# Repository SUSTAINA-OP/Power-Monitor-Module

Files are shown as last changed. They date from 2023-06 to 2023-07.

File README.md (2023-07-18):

<html lang="en">

<head>
	<meta charset="uft-8">
	<meta name="author" content="Masato Kubotera">
    <meta name="description" content="">
</head>

<body>
    <p><strong>This product is currently under development!</strong></p>
	<h1>Power Monitor Module</h1>
        <p>
            This product is a high-side sensing current/voltage monitor module. The sensing voltage is 0~36V and the current is ±20A. The operating voltage is 2.7~5.5V, and these values are available via I<sup>2</sup>C I/F. The slave address is selectable on the board, and up to 16 modules in total are connected.<br>
            <br>
            This product has been verified to be able to acquire current and voltage values using the following Arduino library.
            <ul>
                <li><a href="https://github.com/asukiaaa/INA226_asukiaaa">asukiaaa/INA226_asukiaaa</a></li>
            </ul>
            SUSTAINA-OP<sup>TM</sup> connects to Jetson Xavier NX through a carrier board and obtains values using the following library.
            <ul>
                <li><a href="https://github.com/hiroki-0001/INA226_Library">hiroki-0001/INA226_Library</a></li>
            </ul>
        </p>
	<h2>Features Rev. 2</h2>
        <p>
            <table>
                <tr>
                    <th>Top Surface of PCB</th>
                    <th>Bottom Surface of PCB</th>
                    <th>Assembled Electronic Components</th>
                </tr>
                <tr>
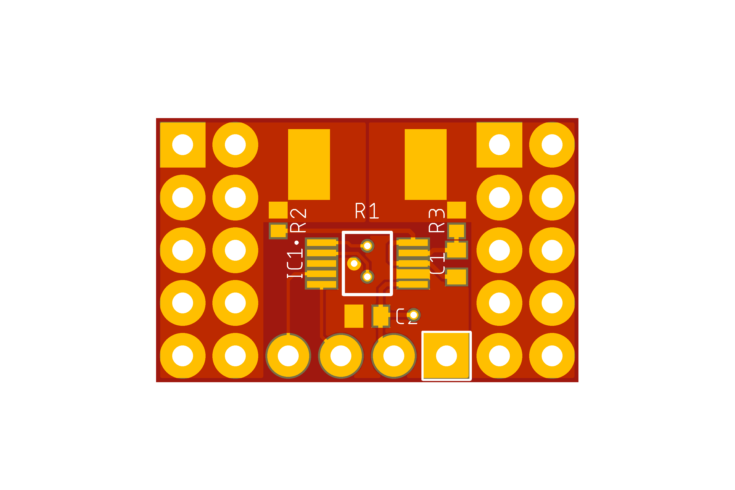
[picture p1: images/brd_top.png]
                    <td></td>
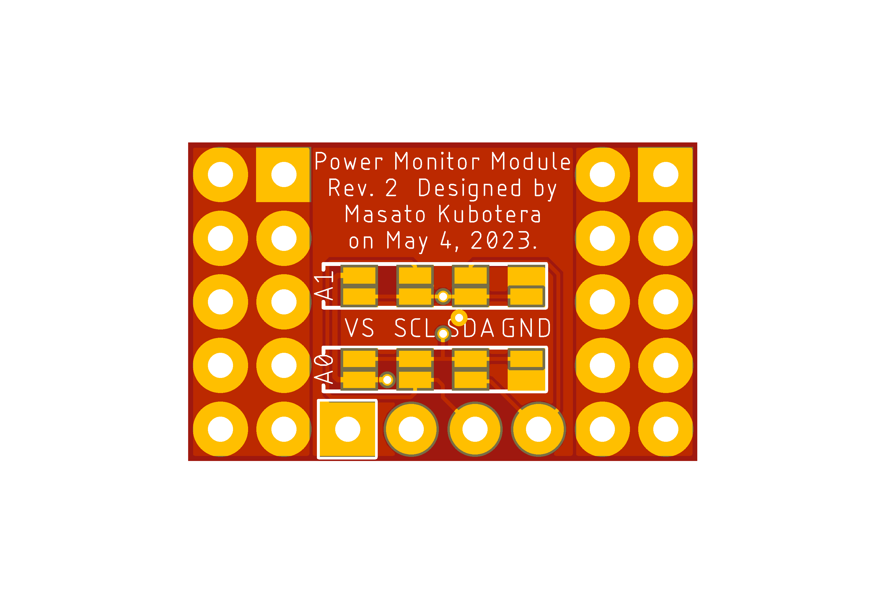
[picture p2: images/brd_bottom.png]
                    <td></td>
                    <td></td>
                </tr>
            </table>
        </p>
    <h3>PCB</h3>
        <p>
            <ul>
                <li>8" x 5" (20.32mm x 12.7mm) PCB layout</li>
                <li>1" (2.54mm) pitch through-holes for pin headers
                    <ul>
                        <li>2 x 5 pin headers - 1
                            <ul>
                                <li><strong>VIN+</strong>: Power input side</li>
                            </ul>
                        </li>
                        <li>2 x 5 pin headers - 2
                            <ul>
                                <li><strong>VIN-</strong>: Load side</li>
                            </ul>
                        </li>
                        <li>1 x 4 pin headers: I<sup>2</sup>C Interface
                            <ul>
                                <li><strong>SDA</strong>: Serial bus data line</li>
                                <li><strong>SCL</strong>: Serial bus clock line</li>
                                <li><strong>VS</strong>: Supply voltage</li>
                                <li><strong>GND</strong>: Common Ground</li>
                            </ul>
                        </li>
                    </ul>
                </li>
            </ul>
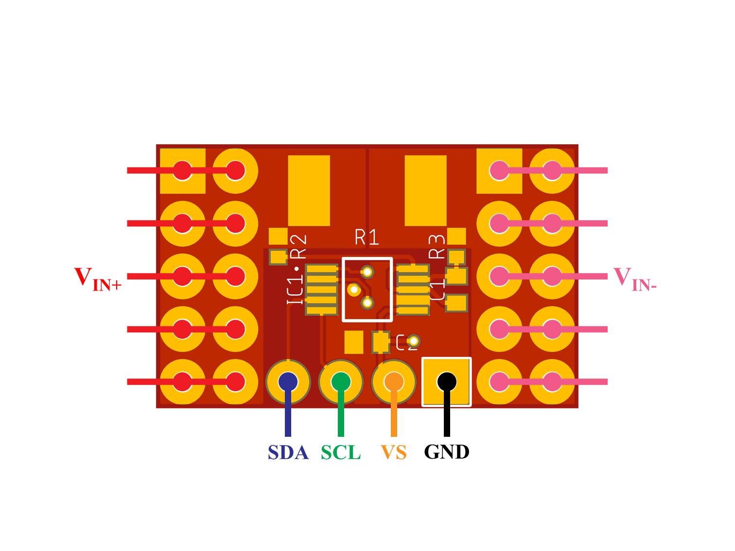
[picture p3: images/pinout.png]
            
        </p>
    <h3><a href="https://www.ti.com/product/en-us/INA226">Texas Instruments INA226</a></h3>
        <p>
            <ul>
                <li>Bus voltage sensing from 0 V to 36 V</li>
                <li>Power-supply operation: 2.7 V to 5.5 V</li>
                <li>High accuracy:
                    <ul>
                        <li>Gain error: 0.1% (maximum)</li>
                        <li>Offset: 10 μV (maximum)</li>
                    </ul>
                </li>
            </ul>
            Note: The I<sup>2</sup>C address of this product is selectable from 16 addresses by the short lands on the board.
        <p>
	<h2>Development Environments</h2>
    <p>
        This product is designed with the following software.
            <ul>
                <li><a href="https://www.autodesk.com/products/eagle/overview">Autodesk Eagle 9.6.2</a></li>
            </ul>
    </p>
    <h2>Repository Contents</h2>
        <p>
            <dl>
                <dt><a href="/images">\images</a></dt>
                <dd>PCB preview images and capture of design screen</dd>
                <dt><a href="/libraries">\libraries</a></dt>
                <dd>Libraries used in Autodesk Eagle design</dd>
                <dt><a href="/pcb_order">\pcb_order</a> </dt>
                <dd>Gerber data and documentation for ordering PCB</dd>
                <dt><a href="/schematic.pdf">schematic.pdf</a></dt>
                <dd>Circuit diagram of this product</dd>
                <dt>*.brd</dt>
                <dd>Board wiring design file by Autodesk Eagle</dd>
                <dt>*.sch</dt>
                <dd>Circuit diagram design file by Autodesk Eagle</dd>
                <dt><a href="/.gitignore">.gitignore</a></dt>
                <dd>A file that tells Git not to track a particular file</dd>            <dt><a href="/LICENSE">LICENSE</a></dt>
                <dd>License to use this product</dd>
            </dl>
        </p>
    <h2>Documentation</h2>
        <p>
            The following documents are available for this product.
            <ul>
                <li><a href="/pcb_order/README.md">\pcb_order\README.md</a>: Information for ordering the PCB or PCBA</li>
            </ul>
        </p>
    <h2>References</h2>
        <p>
            This product was designed with reference to the following products.
            <ul>
                <li><a href="https://www.ti.com/tool/ja-jp/INA226EVM">Texas Instruments INA226EVM: INA226 evaluation module</a></li>
                <li><a href="https://strawberry-linux.com/catalog/items?code=12031">Strawberry Linux INA226: I2C digital current, voltage, and power meter module (up to 20A)</a></li>
            </ul>
        </p>
    <h2>Contact</h2>
        <p>
            If you have any questions, please contact the designer of this product, Masato Kubodera, by <a href="mailto:masato.kubotera@sustaina-op.com">e-mail</a>.<br>
            E-mail: <a href="mailto:masato.kubotera@sustaina-op.com">masato.kubotera@sustaina-op.com</a>
        </p>
    <h2>License Information</h2>
        <p>
            This product is open source. Please review the <a href="/LICENSE">LICENSE</a> for license information.<br>
            <br>
            This product by Masato Kubotera is licensed under a <a href="http://creativecommons.org/licenses/by-nc-sa/4.0/">Creative Commons Attribution-NonCommercial-ShareAlike 4.0 International License</a>.
        </p>
</body>
</html>

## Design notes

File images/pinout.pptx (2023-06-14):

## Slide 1


VIN+

VIN-

SDA

SCL

GND

VS

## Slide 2

SDA

SCL

VS

GND

Power Monitor Module

VIN+

VIN-

Power Supply
0 V to 36V

GND

Load
Max. 20A

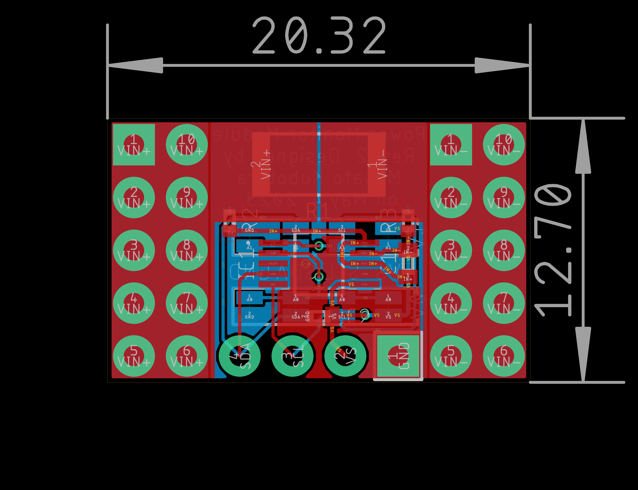
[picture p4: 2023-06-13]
images/brd.png

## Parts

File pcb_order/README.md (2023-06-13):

<html lang="en">

<head>
	<meta charset="uft-8">
	<meta name="author" content="Masato Kubotera">
    <meta name="description" content="">
</head>

<body>
	<h1>PCB / PCBA Order</h1>
        <p>
            PCB/PCBA ordering were outsourced to <a href="https://jlcpcb.com/">JLCPCB</a>.<br>
            The following files were used to generate files for PCB/PCBA orders.
            <ul>
                <li>Eagle Design File:
                    <a href="https://github.com/JLCPCB/jlcpcb-eagle/blob/master/design%20rules/jlcpcb-2layers.dru">jlcpcb-2layers.dru</a>
                </li>
                <li>Eagle CAM File:
                    <a href="https://github.com/JLCPCB/jlcpcb-eagle/blob/master/cam/jlcpcb_2_layer_v9.cam">jlcpcb_2_layer_v9.cam</a>
                </li>
                <li>BOM/CPL Exporter ULPs:
                    <a href="https://github.com/JLCPCB/jlcpcb-eagle/blob/master/ulps/jlcpcb_smta_exporter.ulp">jlcpcb_smta_exporter.ulp</a>
                </li>
            </ul>
            These are distributed in <a href="https://github.com/JLCPCB/jlcpcb-eagle">github.com/JLCPCB/jlcpcb-eagle</a>.<br>
        </p>
    <h2>PCB Order Specifications</h2>
        <p>           
            <table>
                <tr>
                    <th>PCB Top Image</th>
                    <th>PCB Bottom Image</th>
                </tr>
                <tr>
                    <td></td>
                    <td></td>
                </tr>
            </table>
            The following  files used to order the PCB and their specifications. 
            <ul>
                <li>Gerber data: <a href="Gerber_date.zip">Gerber_date.zip</a></li>
            </ul>
            <details close>
                <summary>Click for more specifications</summary>
                <ul>                
                    <li>Base Material: FR-4</li>
                    <li>Layers: 2</li>
                    <li>Dimension: 20.32 mm* 12.7 mm</li>
                    <li>Product Type: Industrial/Consumer electronics</li>
                    <li>Different Design: 1</li>
                    <li>Delivery Format: Single PCB</li>
                    <li>PCB Thickness: 1.6</li>
                    <li>Impedance Control: no</li>
                    <li>PCB Color: Red</li>
                    <li>Silkscreen: White</li>
                    <li>Surface Finish: HASL(with lead)</li>
                    <li>Outer Copper Weight: 1 oz</li>
                    <li>Via Covering: Tented</li>
                    <li>Board Outline Tolerance: ±0.2mm(Regular)</li>
                    <li>Confirm Production file: No</li>                
                    <li>Remove Order Number: Yes</li>
                    <li>Deburring/Edge rounding: No</li>
                    <li>Flying Probe Test: Fully Test</li>
                    <li>Gold Fingers: No</li>
                    <li>Castellated Holes: No</li>
                    <li>4-Wire Kelvin Test: No</li>
                    <li>Paper between PCBs: No</li>
                    <li>Appearance Quality: IPC Class 2 Standard</li>
                    <li>Silkscreen Technology: Ink-jet/Screen Printing</li>
                    <li>Package Box: With JLCPCB logo</li>
                </ul>
            </details>
        </p>
    <h2>PCBA Order Specifications</h2>
        <p>
            <table>
                <tr><th>PCBA Image</th></tr>
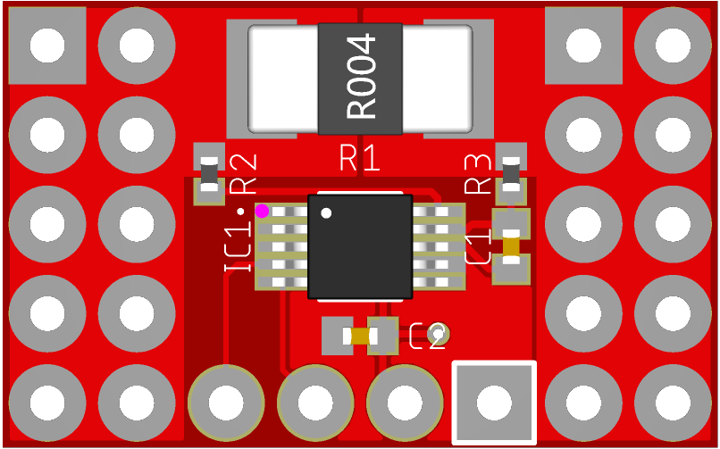
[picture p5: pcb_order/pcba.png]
                <tr><td></td></tr>
            </table>
            The following files used to order the PCBA and their specifications.
            <ul>
                <li>BOM File: <a href="Power-Monitor-Module_top_bom.csv">Power-Monitor-Module_top_bom.csv</a></li>
                <li>CPL File: <a href="Power-Monitor-Module_top_cpl.csv">Power-Monitor-Module_top_cpl.csv</a></li>
            </ul>
            The following parts are attached in the PCBA.
            <table>
                <tr>
                    <th>Part Image</th>
                    <th>Top Designator</th>
                    <th>MFR.Part #</th>
                    <th>JLCPCB Part #</th>
                    <th>Manufacturer</th>
                    <th>Part Detail</th>
                </tr>
                <tr>
                    <td></td>
                    <td>C1,C2</td>
                    <td>CC0402JRX7R7BB104</td>
                    <td><a href="https://jlcpcb.com/partdetail/Yageo-CC0402JRX7R7BB104/C541464">C541464</a></td>
                    <td>Murata Electronics</td>
                    <td>Multilayer Ceramic Capacitor SMD 100nF 16V ±5% X7R 0402</td>
                </tr>
                <tr>
                    <td></td>
                    <td>IC1</td>
                    <td>INA226AIDGSR</td>
                    <td><a href="https://jlcpcb.com/partdetail/TexasInstruments-INA226AIDGSR/C49851">C49851</a></td>
                    <td>Texas Instruments</td>
                    <td>Output Current/Voltage/Power Monitor 36V 16-bit MSOP-10</td>
                </tr>
                <tr>
                    <td></td>
                    <td>R1</td>
                    <td>LMP25NF3P0R002S</td>
                    <td><a href="https://jlcpcb.com/partdetail/Prosemi-LMP25NF3P0R002S/C2838967">C2838967</a></td>
                    <td>prosemi</td>
                    <td>Current Sensing Resistors SMD 2mΩ 3W ±1% 2512</td>
                </tr>
                <tr>
                    <td></td>
                    <td>R2,R3</td>
                    <td>RC0402FR-074R7L</td>
                    <td><a href="https://jlcpcb.com/partdetail/Yageo-RC0402FR074R7L/C137962">C137962</a></td>
                    <td>YAGEO</td>
                    <td>Thick Film Resistor SMD 4.7Ω 62.5mW ±1% 0402</td>
                </tr>
            </table>
            These selected parts are listed in <a href="bom.xls">bom.xls</a>.<br>
            <details close>
                <summary>Click for more specifications</summary>
                <ul>                
                    <li>PCBA Type: Economic</li>
                    <li>Assembly Side: Top Side</li>
                    <li>Tooling holes: Added by JLCPCB</li>
                    <li>Confirm Parts Placement: No</li>
                </ul>
            </details>
        </p>
    </body>
</html>

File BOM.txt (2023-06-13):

Qty Value     Device     Package   Parts                                  Description                
1   0.002     R-US_R2512 R2512     R1                                     RESISTOR, American symbol  
2   0.1u      C-EUC0402  C0402     C1, C2                                 CAPACITOR, European symbol 
1   1X4P      1X4P       1X4P      P3                                                                
2   2X5P      2X5P       2X5P      P1, P2                                                            
2   4.7       R-US_R0402 R0402     R2, R3                                 RESISTOR, American symbol  
1   INA226    INA226     MSOP-10   IC1                                                               
8   SHORTLAND SHORTLAND  SHORTLAND JP1, JP2, JP3, JP4, JP5, JP6, JP7, JP8

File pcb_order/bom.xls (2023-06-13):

Comment | Designator | Footprint | JLCPCB Part #
0.002 | R1 | R2512 | C2838967
0.1u | C1,C2 | C0402 | C541464
4.7 | R2,R3 | R0402 | C137962
INA226 | IC1 | INA226 | C49851

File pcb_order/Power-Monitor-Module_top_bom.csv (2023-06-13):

Comment | Designator | Footprint | LCSC Part #
0.1u | C1 C2 | C0402 | C541464
0.002 | R1 | R2512 | C2838967
4.7 | R2 R3 | R0402 | C137962
INA226 | IC1 | MSOP-10 | C49851

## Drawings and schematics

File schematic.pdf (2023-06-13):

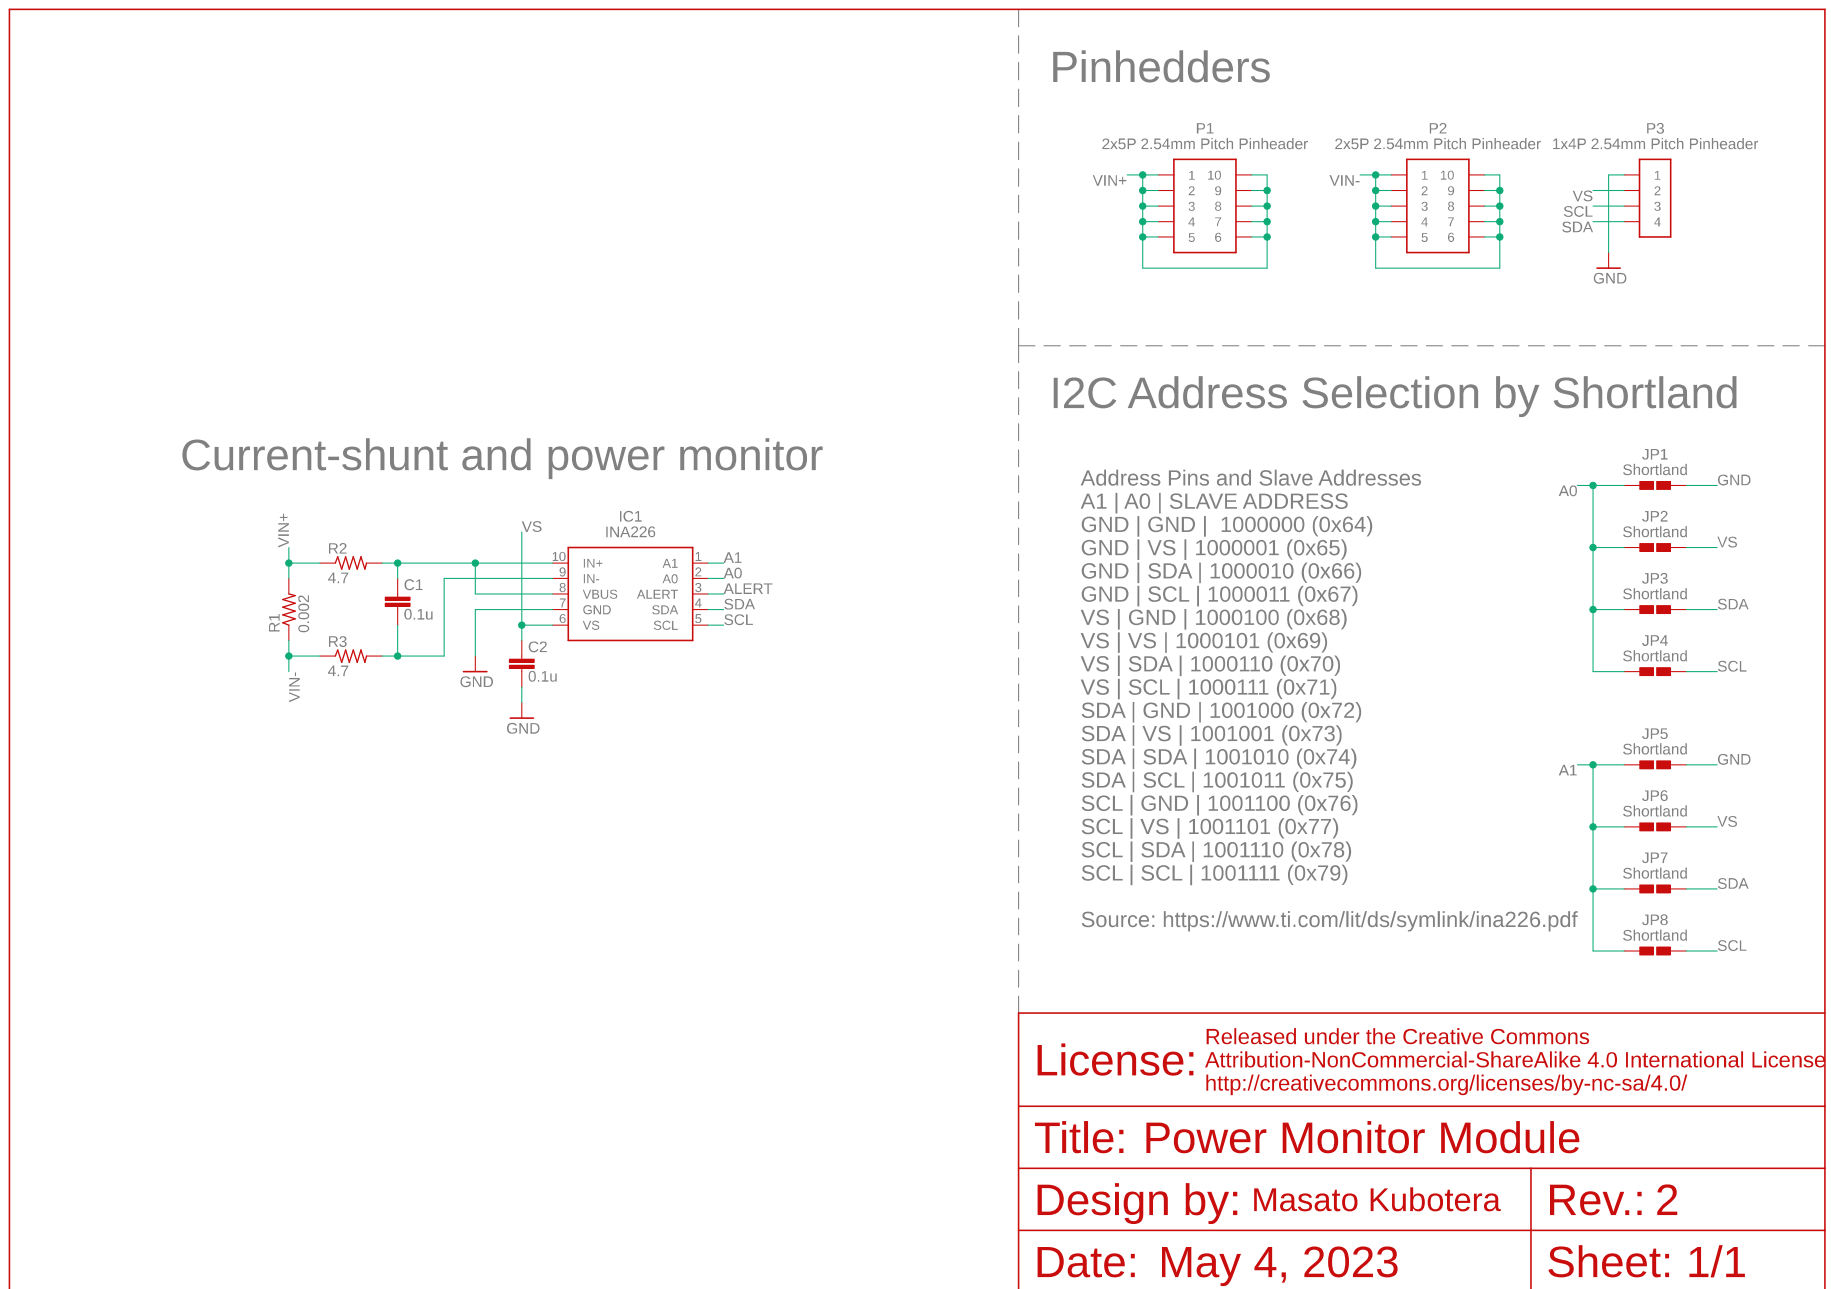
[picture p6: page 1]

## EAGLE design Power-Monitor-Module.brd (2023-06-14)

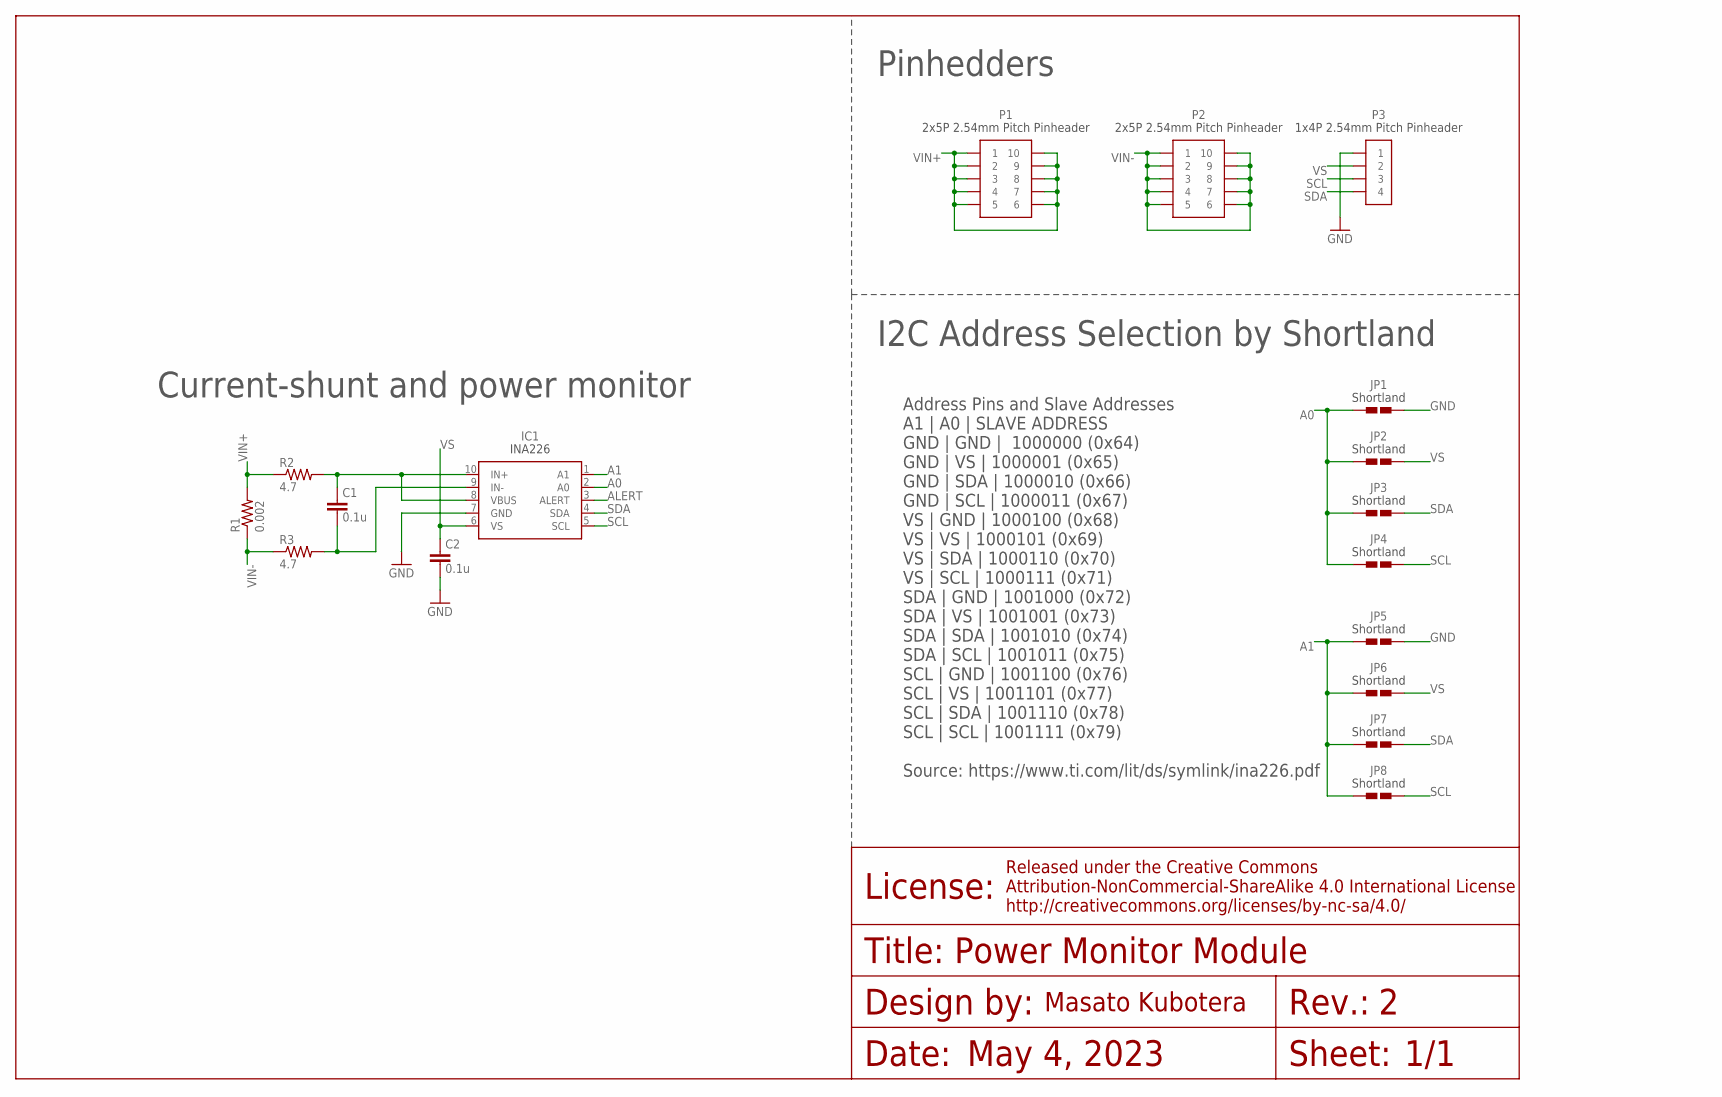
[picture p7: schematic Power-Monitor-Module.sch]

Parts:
C1, C2: 0.1u; C0402
IC1: INA226; MSOP-10
JP1, JP2, JP3, JP4, JP5, JP6, JP7, JP8: SHORTLAND
P1, P2: 2X5P
P3: 1X4P
R1: 0.002; R2512
R2, R3: 4.7; R0402

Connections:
A0: IC1.2 (A0), JP1.1, JP2.1, JP3.1, JP4.1
A1: IC1.1 (A1), JP5.1, JP6.1, JP7.1, JP8.1
ALERT: IC1.3 (ALERT)
GND: C2.2, IC1.7 (GND), JP1.2, JP5.2, P3.1
IN+: C1.1, IC1.8 (VBUS), IC1.10 (IN+), R2.2
IN-: C1.2, IC1.9 (IN-), R3.2
SCL: IC1.5 (SCL), JP4.2, JP8.2, P3.3
SDA: IC1.4 (SDA), JP3.2, JP7.2, P3.4
VIN+: P1.1, P1.2, P1.3, P1.4, P1.5, P1.6, P1.7, P1.8, P1.9, P1.10, R1.2, R2.1
VIN-: P2.1, P2.2, P2.3, P2.4, P2.5, P2.6, P2.7, P2.8, P2.9, P2.10, R1.1, R3.1
VS: C2.1, IC1.6 (VS), JP2.2, JP6.2, P3.2

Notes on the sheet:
I2C Address Selection by Shortland
Pinhedders
Current-shunt and power monitor
May 4, 2023
Power Monitor Module
1/1
Address Pins and Slave Addresses A1 | A0 | SLAVE ADDRESS GND | GND | 1000000 (0x64) GND | VS | 1000001 (0x65) GND | SDA | 1000010 (0x66) GND | SCL | 1000011 (0x67) VS | GND | 1000100 (0x68) VS | VS | 1000101 (0x69) VS | SDA | 1000110 (0x70) VS | SCL | 1000111 (0x71) SDA | GND | 1001000 (0x72) SDA |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

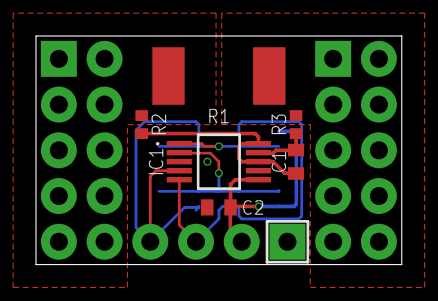
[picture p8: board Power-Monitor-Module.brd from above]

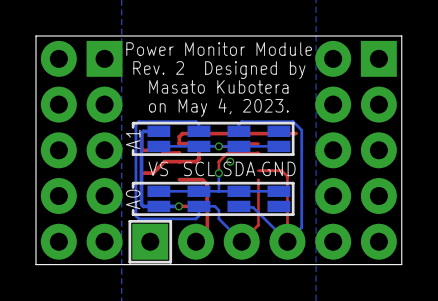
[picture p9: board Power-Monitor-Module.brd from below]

Board: 2 copper layers, 20.3 x 12.7 mm, 17 parts (8 on the bottom side), 10 nets.

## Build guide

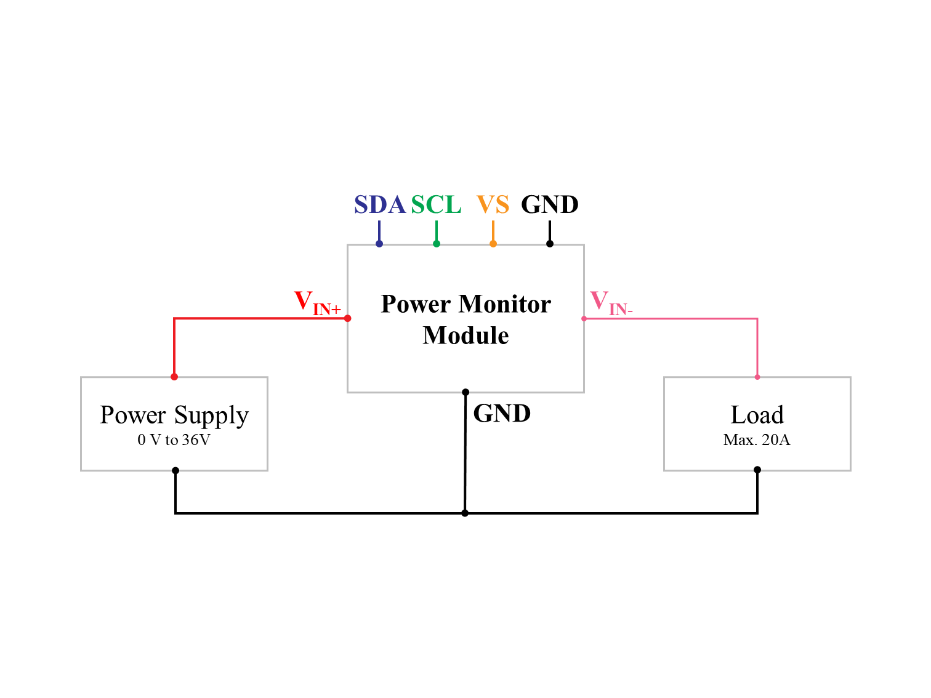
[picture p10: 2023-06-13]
images/wiring_diagram.png

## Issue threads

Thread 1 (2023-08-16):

銅箔圧2ozに対応させる

MasatoKubotera, 2023-08-16:

MasatoKubotera, 2023-09-06:
ボトム面にシャント抵抗を配置することで，最大パターン幅を確保できる．

以下，構想配置図．

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

MasatoKubotera, 2023-09-06:
両面の部品実装について，JLCPCBに見積もりをかけた．
基板銅箔厚は2oZとしている．

以下，Rev.3（仮）見積もり．＄164.51／30枚．￥806.34／枚．
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

以下，Rev. 2の注文詳細．＄62.1／30枚．￥304.381／枚．
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

MasatoKubotera, 2023-09-07:
Layout Guidelines
https://www.ti.com/jp/lit/ds/symlink/ina226.pdf#page=30

> Connect the input pins (IN+ and IN-) to the sensing resistor using a Kelvin connection or a 4-wire connection. These connection techniques ensure that only the current-sensing resistor impedance is detected between the input pins. Poor routing of the current-sensing resistor commonly results in additional resistance present between the input pins. Given the very low ohmic value of the current-sensing resistor, any additional high-current carrying impedance causes significant measurement errors. Place the power-supply bypass capacitor as close as possible to the supply and ground pins.

> 入力ピン（IN+ と IN-）を、ケルビン接続または 4 線接続で検出抵抗に接続する。これらの接続方法は、電流検出抵抗のインピーダンスのみが入力ピン間で検出されることを保証する。電流検出抵抗の配線が悪いと、一般的に入力ピン間に追加の抵抗が存在することになる。電流検出抵抗のオーミック値が非常に低いため、大電流を流すインピーダンスを追加すると、測定誤差が大きくなる。電源バイパス・コンデンサは、電源ピンとグランド・ピンのできるだけ近くに配置してください。

MasatoKubotera, 2023-09-07:
ケルビン接続：https://www.macnica.co.jp/business/semiconductor/articles/basic/117777/

MasatoKubotera, 2023-09-07:
ネットで調べると半額以下で売っている商品もありますが、どう違うのですか？ 2022-11-12更新
https://strawberry-linux.com/support/12031/115945

MasatoKubotera, 2023-09-07:
入力ピン（IN+，IN-）についてチップから抵抗までの距離を等しくなるように配置してみた．

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

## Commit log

2023-04-23 Initial Upload
    [Power-Monitor-Module.brd, Power-Monitor-Module.sch, Power-Monitor-Module_top_bom.csv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]
2023-04-28 Add information on ordering PCB or PCBA to READEME
2023-06-13 Made Rev.2 with the measurement IC changed to INA226.
    [Power-Monitor-Module.brd, Power-Monitor-Module.sch, Power-Monitor-Module_top_bom.csv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]
2023-06-14 Changed the color of the board preview to a shade closer to the actual color.
    [Power-Monitor-Module.brd]

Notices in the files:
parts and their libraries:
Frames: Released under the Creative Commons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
